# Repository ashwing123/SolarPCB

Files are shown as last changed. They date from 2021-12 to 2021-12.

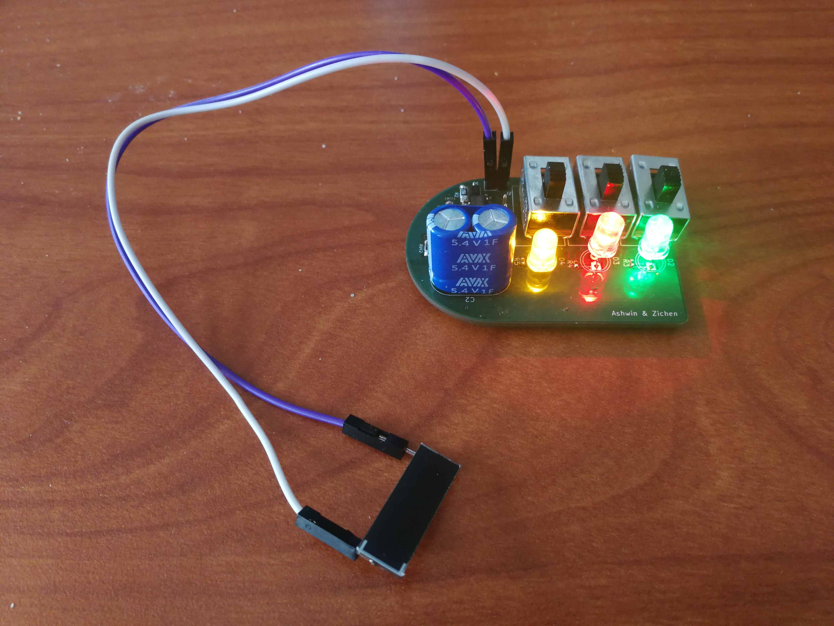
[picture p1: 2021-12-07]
PCB working.jpeg

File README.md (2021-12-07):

# SolarPCB
Created a Printed Circuit Board (PCB) that harvests energy from a solar cell, with the main component being a bq25504 microcontroller that controls the overvoltage and undervoltage for effective charge storage in a 1F supercapacitor. Designed the schematic, layout, and created custom footprints for supercapacitor, switches, and other components.

Schematic:



Layout:



Working PCB:

image of PCB connected and soldered
image of PCB working with lights on

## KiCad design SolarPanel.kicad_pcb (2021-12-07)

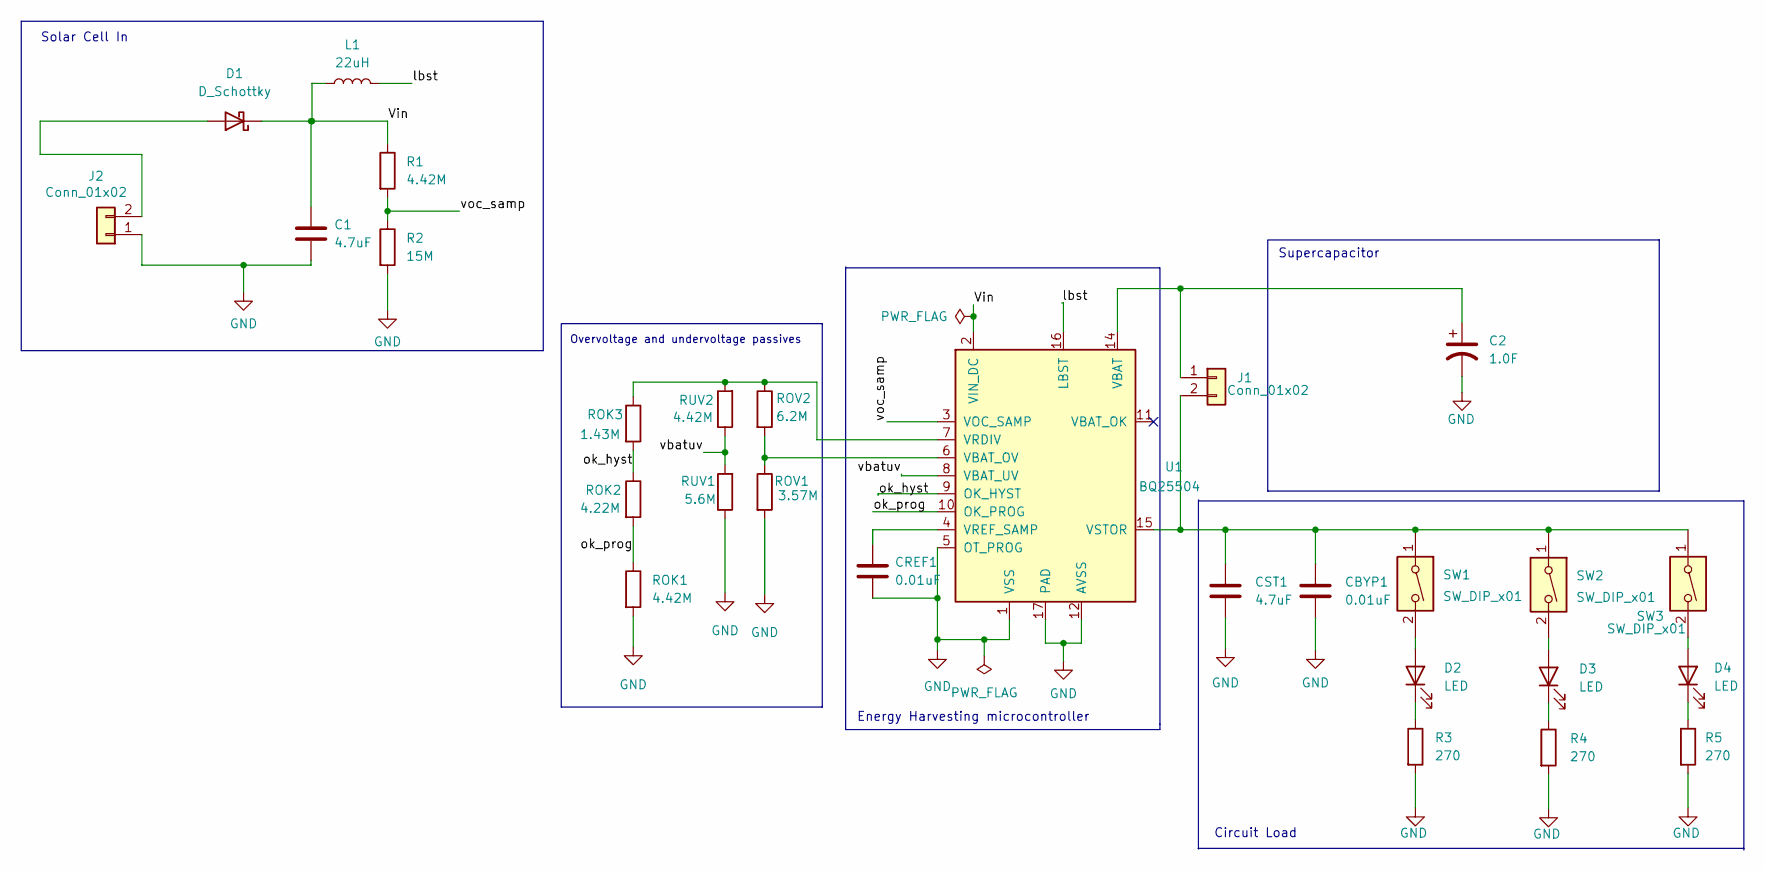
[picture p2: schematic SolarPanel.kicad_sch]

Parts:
C1: 4.7uF; C_0402_1005Metric
C2: 1.0F; SCAP
CBYP1: 0.01uF; C_0805_2012Metric
CREF1: 0.01uF; C_0805_2012Metric
CST1: 4.7uF; C_0402_1005Metric
D1: D_Schottky; D_SOD-123
D2, D3, D4: LED; LED_D5.0mm_Clear
J1, J2: Conn_01x02; PinHeader_1x02_P2.54mm_Vertical
L1: 22uH; L_1812_4532Metric
R1: 4.42M; R_1206_3216Metric
R2: 15M; R_1206_3216Metric
R3, R4, R5: 270; R_0402_1005Metric
ROK1: 4.42M; R_1206_3216Metric
ROK2: 4.22M; R_0805_2012Metric
ROK3: 1.43M; R_0603_1608Metric
ROV1: 3.57M; R_0805_2012Metric
ROV2: 6.2M; R_0603_1608Metric
RUV1: 5.6M; R_0603_1608Metric
RUV2: 4.42M; R_1206_3216Metric
SW1, SW2, SW3: SW_DIP_x01; Switch1
U1: BQ25504; QFN-16-1EP_3x3mm_P0.5mm_EP1.9x1.9mm

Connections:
/Vin: C1.1, D1.1 (K), L1.1, R1.1, U1.2 (VIN_DC)
/lbst: L1.2, U1.16 (LBST)
/ok_hyst: ROK2.1, ROK3.2, U1.9 (OK_HYST)
/ok_prog: ROK1.1, ROK2.2, U1.10 (OK_PROG)
/vbatuv: RUV1.2, RUV2.1, U1.8 (VBAT_UV)
/voc_samp: R1.2, R2.1, U1.3 (VOC_SAMP)
GND: C1.2, C2.2, CBYP1.2, CREF1.2, CST1.2, J2.1, R2.2, R3.2, R4.2, R5.2, ROK1.2, ROV1.2, RUV1.1, U1.1 (VSS), U1.5 (OT_PROG), U1.12 (AVSS), U1.13 (VSS), U1.17 (PAD)
unnamed: C2.1, J1.1, U1.14 (VBAT)
unnamed: CBYP1.1, CST1.1, J1.2, SW1.1, SW2.1, SW3.1, U1.15 (VSTOR)
unnamed: CREF1.1, U1.4 (VREF_SAMP)
unnamed: D1.2 (A), J2.2
unnamed: D2.1 (K), R3.1
unnamed: D2.2 (A), SW1.2
unnamed: D3.1 (K), R4.1
unnamed: D3.2 (A), SW2.2
unnamed: D4.1 (K), R5.1
unnamed: D4.2 (A), SW3.2
unnamed: ROK3.1, ROV2.1, RUV2.2, U1.7 (VRDIV)
unnamed: ROV1.1, ROV2.2, U1.6 (VBAT_OV)

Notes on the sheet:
Solar Cell In
Overvoltage and undervoltage passives
Energy Harvesting microcontroller
Circuit Load
Supercapacitor

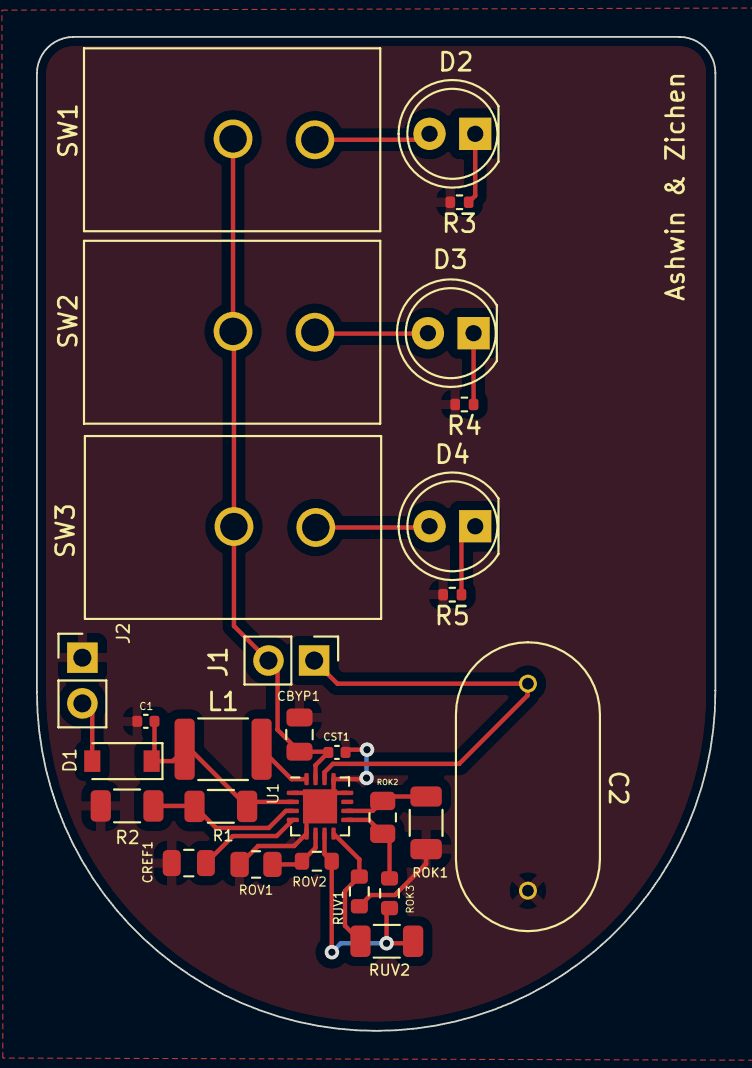
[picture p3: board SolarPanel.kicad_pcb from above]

Board: 2 copper layers, 37.7 x 55.2 mm, 28 parts (0 on the bottom side), 19 nets.
